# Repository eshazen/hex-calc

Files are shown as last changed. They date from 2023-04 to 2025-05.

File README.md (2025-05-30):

# hex-calc

Simple Hex/Binary/Decimal calculator inspired by HP-16C and TI Programmer.

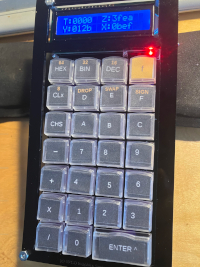
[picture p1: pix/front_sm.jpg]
front view

[large image](pix/front.jpg)

Features:

* Hex / Decimal / Binary display in signed or unsigned mode
  * Entire stack for 8/16 bits, two levels for 32 bits
* four-function two-compliment or unsigned arithmetic
* 8 / 16 / 32 / 64 bit word size
* four-level RPN stack with roll / swap

Runs on ATMeg328 at 8MHz.  Power is 4xAA batteries regulated to 5V.
Industry-standard 16x2 backlit LCD.  Three LEDs:

* Power
* f key (function/shift) active
* signed display mode

Code in <tt>src/calc_hw</tt>.

KiCAD design in <tt>keyboard-pcb</tt>.
<br>Schematic:  [keyboard-pcb.pdf](keyboard-pcb/keyboard-pcb.pdf)

See https://github.com/eshazen/calc-demo-xwin for an X-windows
app written in C which illustrates the general idea.

## Enhancements

Thinking about some added features to support fractional arithmetic
for woodworking.  Display options to round to nearest fraction (1/4,
1/8, 1/16, 1/32, 1/64) and switch between decimal inch, fraction inch
and decimal mm.  Ft/inches another useful display option.

This would involve either floating point or scaled integer math.
For this application the range is pretty limited, maybe 8 ft (~100 in)
max.

Base units could be 2.54e-6 in (1um).  100 inches would require ~25
bits.  

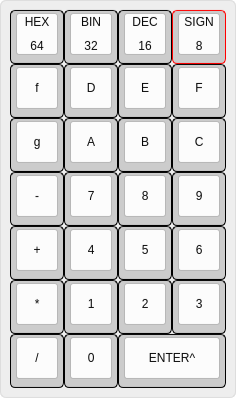
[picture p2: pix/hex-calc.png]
keyboard layout


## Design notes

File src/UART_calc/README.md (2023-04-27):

# UART_calc

This is a test version of the "hex" calculator to test AVR resource use

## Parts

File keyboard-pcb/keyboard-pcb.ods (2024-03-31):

# | Reference | Qty | Value | Footprint | CatNo | Ordered
1 | BT1 | 1 | 4xAAA | AAA_batt_holder:Keystone_4xAAA_2481 | BC4AAAPC-ND | DK
2 | C1, C3 | 2 | 0.1uF | Capacitor_THT:C_Disc_D5.0mm_W2.5mm_P2.50mm
3 | C2 | 1 | 10uF | Capacitor_THT:C_Disc_D5.0mm_W2.5mm_P2.50mm
4 | D1, D2, D11 | 3 | LED | LED_THT:LED_D3.0mm
5 | D3, D4, D5, D6, D7, D8, D9, D10, D12, D13, D14, D15, D16, D17, D18, D19, D20, D21, D22, D23, D24, D25, D26, D27, D28, D29, D30 | 27 | 1N914 | Diode_THT:D_DO-35_SOD27_P7.62mm_Horizontal |  | DK
6 | J1 | 1 | Conn_02x03_Odd_Even | Connector_PinHeader_2.54mm:PinHeader_2x03_P2.54mm_Vertical
7 | R1, R2, R3, R5 | 4 | 470 | Resistor_THT:R_Axial_DIN0207_L6.3mm_D2.5mm_P7.62mm_Horizontal
8 | R4 | 1 | 10k | Resistor_THT:R_Axial_DIN0207_L6.3mm_D2.5mm_P7.62mm_Horizontal
9 | RV1 | 1 | 10k | Potentiometer_THT:Potentiometer_Bourns_3266P_Horizontal |  | DK
10 | SW1, SW2, SW3, SW4, SW6, SW7, SW8, SW9, SW10, SW11, SW12, SW13, SW14, SW15, SW16, SW17, SW18, SW19, SW20, SW21, SW22, SW23, SW24, SW25, SW26, SW27 | 26 | SW_Push | Button_Switch_Keyboard:SW_Cherry_MX_1.00u_PCB |  | Amazon
11 | SW5 | 1 | SW_SPST | my_switch:ANT11TFHQE_switch | 2449-ANT11TFHQE-ND | DK
12 | SW28 | 1 | SW_Push | Button_Switch_Keyboard:SW_Cherry_MX_2.00u_PCB |  | Stock
13 | U2 | 1 | R1500H | Package_TO_SOT_SMD:SOT-89-5_Handsoldering | 2129-R1500H050B-T1-FECT-ND | DK
14 | U3 | 1 | ATmega328-P | Package_DIP:DIP-28_W7.62mm |  | DK
15 | U4 | 1 | RC1602A | Display:WC1602A |  | Amazon

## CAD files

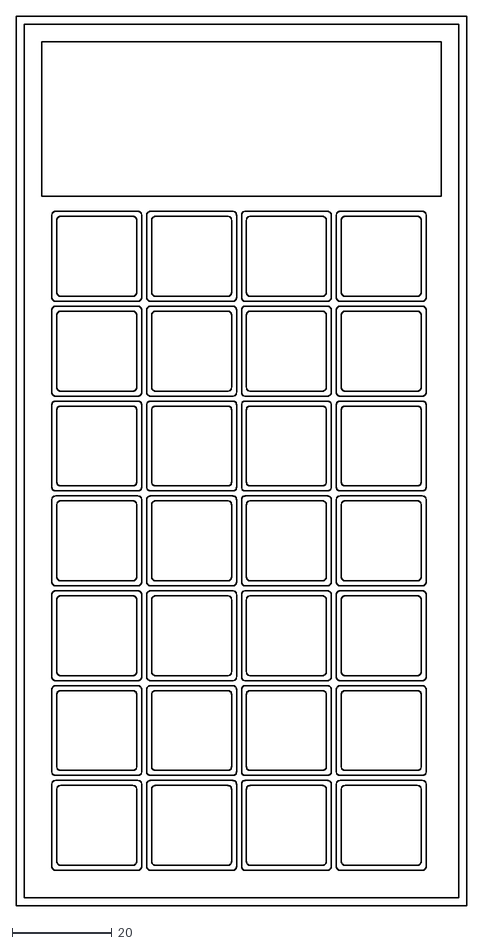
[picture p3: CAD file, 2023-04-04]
3D/calc.dxf
90.2 x 178.2

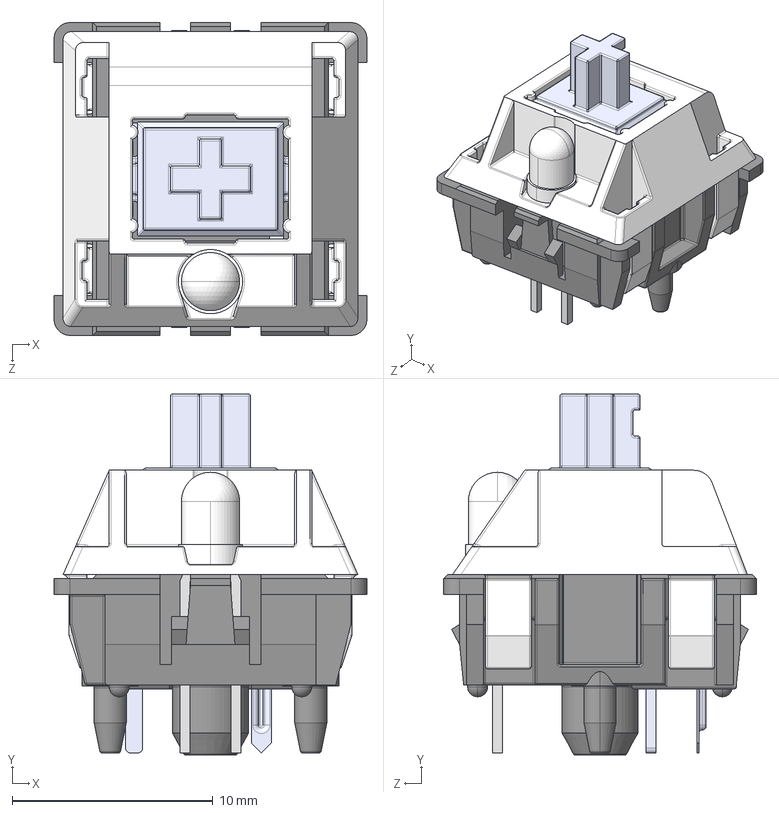
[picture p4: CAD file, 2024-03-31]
keyboard-pcb/3D/Cherry MX.STEP
15.6 x 18.0 x 15.6 mm
Bottom
Pulsador
Top
Pieza5^Cherry MX
Pin1
Pin2
Led 3mm_trans

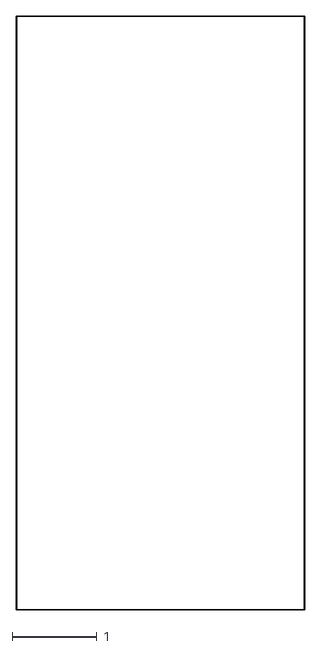
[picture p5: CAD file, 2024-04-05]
keyboard-pcb/DXF/keyboard-pcb-Edge_Cuts.dxf
3.40 x 7.00

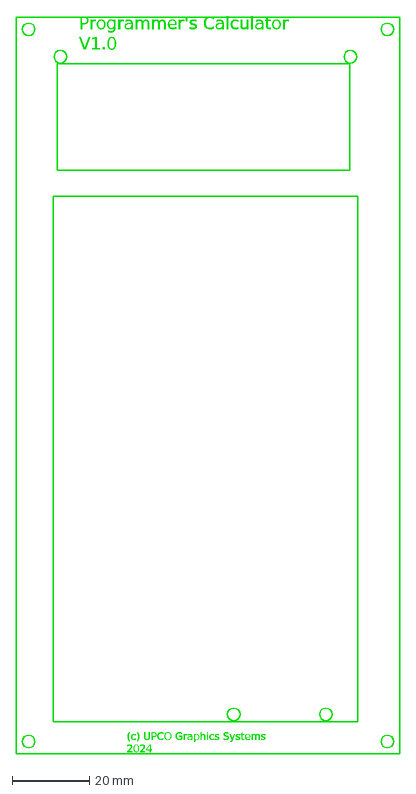
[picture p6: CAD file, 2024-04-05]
keyboard-pcb/DXF/top_plate.dxf
Programmer's Calculator V1.0
(c) UPCO Graphics Systems 2024

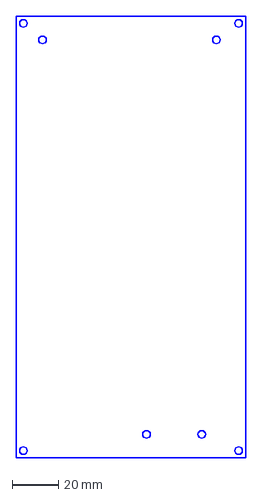
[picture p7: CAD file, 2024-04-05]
keyboard-pcb/DXF/bottom_plate.dxf
99.1 x 190.5 mm

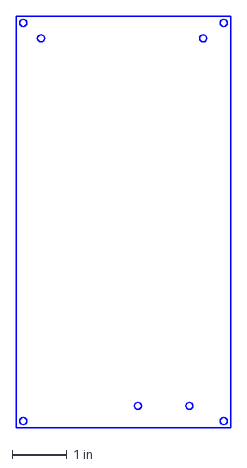
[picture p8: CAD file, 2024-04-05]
keyboard-pcb/DXF/board-mech.dxf
3.90 x 7.50 in

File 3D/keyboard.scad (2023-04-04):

keys = [ [ ["HEX","64"], ["BIN","32"], ["DEC","16"], ["SIGN","8"]],
	 [ ["f", ""],    ["D", ""],    ["E", ""],    ["F", ""]],
	 [ ["g", ""],    ["A", ""],    ["B", ""],    ["C", ""]],
	 [ ["-", ""],    ["7", ""],    ["8", ""],    ["9", ""]],
	 [ ["+", ""],    ["4", ""],    ["5", ""],    ["6", ""]],
	 [ ["*", ""],    ["1", ""],    ["2", ""],    ["3", ""]],
//	 [ ["/", ""],    ["0", ""],    ["ENT", ""],    ["ER", ""]]
	 ];

module keyboard() {

     dx = 19;
     dy = 19;

     x = 0;
     y = 0;

     for( y=[0:len(keys)-1], x=[0:len(keys[y])-1]) {
	  row = keys[y];
	  key = row[x];
//	  echo( "row =", row, " key=", key);
	  translate( [x*dx,-y*dy,0])
	       makeKey( r4_f, r4_b, x1_00, x1_00, key[0], key[1]);
     }

     // last row by hand
     translate( [0, -6*dx, 0]) {
	  makeKey( r4_f, r4_b, x1_00, x1_00, "/");
	  translate( [dx, 0, 0])
	  makeKey( r4_f, r4_b, x1_00, x1_00, "0");
	  translate( [2.5*dx, 0, 0]) {
	       makeKey( r4_f, r4_b, x1_00, x2_00, "ENTER");
	  }
     }
}

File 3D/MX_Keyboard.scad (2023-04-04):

// Cherry MX standard (OEM) measurements
// Measurements and key sizes collected from:
// http://blog.maxkeyboard.com/dwkb/keycap-profile-size-information/
// https://support.wasdkeyboards.com/hc/en-us/articles/115009701328-Keycap-Size-Compatibility
// http://i.imgur.com/K5kui2s.jpg
// Visual information of key text collected from:
// https://www.keychatter.com/wp-content/uploads/2014/07/filco-standard-layout.png
// row number - front and back heights
r1_f = 10.1;
r1_b = 7.9;
r2_f = 9.3;
r2_b = 8;
r3_f = 9.3;
r3_b = 9;
r4_f = 10.8;
r4_b = 11.4;

// width measurement
x1_00 = 18;
x1_25 = 22.8;
x1_50 = 27.5;
x1_75 = 32.3;
x2_00 = 37.1;
x2_25 = 41.8;
x2_75 = 51.4;
space = 118.1;

// spacing measurement
normalSpacing = 12;
spacebarSpacing = 50; // default x6_25
spacebarX6Spacing = 49;
spacebarX6_5Spacing =  52.5;

// other measurements
rounding = 1.5;
postDiam = 5.54;
crossLong = 4.1;
crossWide = 1.35;

// unspecified details
insetX = 5;
insetYfront = 3;
insetYback = 0.6;
wallThick = 1;
postBottomGap = 2;
topCurveDip = 1;

$fn = 36;

// This function borrowed from OpenSCAD Snippet Pad:
// https://openscadsnippetpad.blogspot.com/2017/05/circle-defined-by-three-points.html
// Finding the Center of a Circle from Three Points.
// Points must not be equal or collinear, - lie on a single straight line 
function circle_by_three_points(A, B, C) =
let (
  yD_b = C.y - B.y,  xD_b = C.x - B.x,  yD_a = B.y - A.y,
  xD_a = B.x - A.x,  aS = yD_a / xD_a,  bS = yD_b / xD_b,
  cex = (aS * bS * (A.y - C.y) + 
  bS * (A.x + B.x) -    aS * (B.x + C.x)) / (2 * (bS - aS)),
  cey = -1 * (cex - (A.x + B.x) / 2) / aS + (A.y + B.y) / 2
)
[cex, cey];
    
// Primary entry point for this library
// keyname is a string, as seen in the else-if chain below
module key(keyname) 
{
         if (keyname == "Escape") makeKey(r4_f, r4_b, x1_00, x1_00, "Esc");
    else if (keyname == "F1") makeKey(r4_f, r4_b, x1_00, x1_00, "F1");
    else if (keyname == "F2") makeKey(r4_f, r4_b, x1_00, x1_00, "F2");
    else if (keyname == "F3") makeKey(r4_f, r4_b, x1_00, x1_00, "F3");
    else if (keyname == "F4") makeKey(r4_f, r4_b, x1_00, x1_00, "F4");
    else if (keyname == "F5") makeKey(r4_f, r4_b, x1_00, x1_00, "F5");
    else if (keyname == "F6") makeKey(r4_f, r4_b, x1_00, x1_00, "F6");
    else if (keyname == "F7") makeKey(r4_f, r4_b, x1_00, x1_00, "F7");
    else if (keyname == "F8") makeKey(r4_f, r4_b, x1_00, x1_00, "F8");
    else if (keyname == "F9") makeKey(r4_f, r4_b, x1_00, x1_00, "F9");
    else if (keyname == "F10") makeKey(r4_f, r4_b, x1_00, x1_00, "F10");
    else if (keyname == "F11") makeKey(r4_f, r4_b, x1_00, x1_00, "F11");
    else if (keyname == "F12") makeKey(r4_f, r4_b, x1_00, x1_00, "F12");
    else if (keyname == "Print Screen") makeKey(r4_f, r4_b, x1_00, x1_00, "Print", "Screen");
    else if (keyname == "Scroll Lock") makeKey(r4_f, r4_b, x1_00, x1_00, "Scroll", "Lock");
    else if (keyname == "Pause") makeKey(r4_f, r4_b, x1_00, x1_00, "Pause", "Break");
    else if (keyname == "`") makeKey(r4_f, r4_b, x1_00, x1_00, "~", "`");
    else if (keyname == "1") makeKey(r4_f, r4_b, x1_00, x1_00, "!", "1");
    else if (keyname == "2") makeKey(r4_f, r4_b, x1_00, x1_00, "@", "2");
    else if (keyname == "3") makeKey(r4_f, r4_b, x1_00, x1_00, "#", "3");
    else if (keyname == "4") makeKey(r4_f, r4_b, x1_00, x1_00, "$", "4");
    else if (keyname == "5") makeKey(r4_f, r4_b, x1_00, x1_00, "%", "5");
    else if (keyname == "6") makeKey(r4_f, r4_b, x1_00, x1_00, "^", "6");
    else if (keyname == "7") makeKey(r4_f, r4_b, x1_00, x1_00, "&", "7");
    else if (keyname == "8") makeKey(r4_f, r4_b, x1_00, x1_00, "*", "8");
    else if (keyname == "9") makeKey(r4_f, r4_b, x1_00, x1_00, "(", "9");
    else if (keyname == "0") makeKey(r4_f, r4_b, x1_00, x1_00, ")", "0");
    else if (keyname == "-") makeKey(r4_f, r4_b, x1_00, x1_00, "_", "-");
    else if (keyname == "=") makeKey(r4_f, r4_b, x1_00, x1_00, "+", "=");
    else if (keyname == "Backspace") makeKey(r4_f, r4_b, x1_00, x2_00, "◄ Backspace", "", normalSpacing);
    else if (keyname == "Insert") makeKey(r4_f, r4_b, x1_00, x1_00, "Insert");
    else if (keyname == "Home") makeKey(r4_f, r4_b, x1_00, x1_00, "Home");
    else if (keyname == "Page Up") makeKey(r4_f, r4_b, x1_00, x1_00, "Page", "Up");
    else if (keyname == "Num Lock") makeKey(r4_f, r4_b, x1_00, x1_00, "Num", "Lock");
    else if (keyname == "Num /") makeKey(r4_f, r4_b, x1_00, x1_00, "/");
    else if (keyname == "Num *") makeKey(r4_f, r4_b, x1_00, x1_00, "*");
    else if (keyname == "Num -") makeKey(r4_f, r4_b, x1_00, x1_00, "-");
    else if (keyname == "Tab") makeKey(r3_f, r3_b, x1_00, x1_50, "Tab");
    else if (keyname == "Q") makeKey(r3_f, r3_b, x1_00, x1_00, "Q", " ");
    else if (keyname == "W") makeKey(r3_f, r3_b, x1_00, x1_00, "W", " ");
    else if (keyname == "E") makeKey(r3_f, r3_b, x1_00, x1_00, "E", " ");
    else if (keyname == "R") makeKey(r3_f, r3_b, x1_00, x1_00, "R", " ");
    else if (keyname == "T") makeKey(r3_f, r3_b, x1_00, x1_00, "T", " ");
    else if (keyname == "Y") makeKey(r3_f, r3_b, x1_00, x1_00, "Y", " ");
    else if (keyname == "U") makeKey(r3_f, r3_b, x1_00, x1_00, "U", " ");
    else if (keyname == "I") makeKey(r3_f, r3_b, x1_00, x1_00, "I", " ");
    else if (keyname == "O") makeKey(r3_f, r3_b, x1_00, x1_00, "O", " ");
    else if (keyname == "P") makeKey(r3_f, r3_b, x1_00, x1_00, "P", " ");
    else if (keyname == "[") makeKey(r3_f, r3_b, x1_00, x1_00, "{", "[");
    else if (keyname == "]") makeKey(r3_f, r3_b, x1_00, x1_00, "}", "]");
    else if (keyname == "\\") makeKey(r3_f, r3_b, x1_00, x1_50, "|", "\\");
    else if (keyname == "Delete") makeKey(r3_f, r3_b, x1_00, x1_00, "Delete");
    else if (keyname == "End") makeKey(r3_f, r3_b, x1_00, x1_00, "End");
    else if (keyname == "Page Down") makeKey(r3_f, r3_b, x1_00, x1_00, "Page", "Down");
    else if (keyname == "Num 7") makeKey(r3_f, r3_b, x1_00, x1_00, "7", "Home");
    else if (keyname == "Num 8") makeKey(r3_f, r3_b, x1_00, x1_00, "8", "▲");
    else if (keyname == "Num 9") makeKey(r3_f, r3_b, x1_00, x1_00, "9", "Pg Up");
    else if (keyname == "Num +") makeKey(r2_f, r3_b, x2_00, x1_00, "+", "", normalSpacing, "vertical");
    else if (keyname == "Caps Lock") makeKey(r2_f, r2_b, x1_00, x1_50, "CapsLock");
    else if (keyname == "A") makeKey(r2_f, r2_b, x1_00, x1_00, "A", " ");
    else if (keyname == "S") makeKey(r2_f, r2_b, x1_00, x1_00, "S", " ");
    else if (keyname == "D") makeKey(r2_f, r2_b, x1_00, x1_00, "D", " ");
    else if (keyname == "F") makeKey(r2_f, r2_b, x1_00, x1_00, "F", "     _");
    else if (keyname == "G") makeKey(r2_f, r2_b, x1_00, x1_00, "G", " ");
    else if (keyname == "H") makeKey(r2_f, r2_b, x1_00, x1_00, "H", " ");
    else if (keyname == "J") makeKey(r2_f, r2_b, x1_00, x1_00, "J", "     _");
    else if (keyname == "K") makeKey(r2_f, r2_b, x1_00, x1_00, "K", " ");
    else if (keyname == "L") makeKey(r2_f, r2_b, x1_00, x1_00, "L", " ");
    else if (keyname == ";") makeKey(r2_f, r2_b, x1_00, x1_00, ":", ";");
    else if (keyname == "'") makeKey(r2_f, r2_b, x1_00, x1_00, "'", "\"");
    else if (keyname == "Enter") makeKey(r2_f, r2_b, x1_00, x2_25, "Enter", "", normalSpacing);
    else if (keyname == "Num 4") makeKey(r2_f, r2_b, x1_00, x1_00, "4", "◄");
    else if (keyname == "Num 5") makeKey(r2_f, r2_b, x1_00, x1_00, "5", "     _");
    else if (keyname == "Num 6") makeKey(r2_f, r2_b, x1_00, x1_00, "6", "►");
    else if (keyname == "Left Shift") makeKey(r1_f, r1_b, x1_00, x2_25, "Shift", "", normalSpacing);
    else if (keyname == "Z") makeKey(r1_f, r1_b, x1_00, x1_00, "Z", " ");
    else if (keyname == "X") makeKey(r1_f, r1_b, x1_00, x1_00, "X", " ");
    else if (keyname == "C") makeKey(r1_f, r1_b, x1_00, x1_00, "C", " ");
    else if (keyname == "V") makeKey(r1_f, r1_b, x1_00, x1_00, "V", " ");
    else if (keyname == "B") makeKey(r1_f, r1_b, x1_00, x1_00, "B", " ");
    else if (keyname == "N") makeKey(r1_f, r1_b, x1_00, x1_00, "N", " ");
    else if (keyname == "M") makeKey(r1_f, r1_b, x1_00, x1_00, "M", " ");
    else if (keyname == ",") makeKey(r1_f, r1_b, x1_00, x1_00, "<", ",");
    else if (keyname == ".") makeKey(r1_f, r1_b, x1_00, x1_00, ">", ".");
    else if (keyname == "/") makeKey(r1_f, r1_b, x1_00, x1_00, "?", "/");
    else if (keyname == "Right Shift") makeKey(r1_f, r1_b, x1_00, x2_75, "Shift", "", normalSpacing);
    else if (keyname == "Up") makeKey(r1_f, r1_b, x1_00, x1_00, "▲");
    else if (keyname == "Num 1") makeKey(r1_f, r1_b, x1_00, x1_00, "1", "End");
    else if (keyname == "Num 2") makeKey(r1_f, r1_b, x1_00, x1_00, "2", "▼");
    else if (keyname == "Num 3") makeKey(r1_f, r1_b, x1_00, x1_00, "3", "Pg Dn");
    else if (keyname == "Num Enter") makeKey(r1_f, r1_b, x2_00, x1_00, "Enter", "", normalSpacing, "vertical");
    else if (keyname == "Ctrl") makeKey(r1_f, r1_b, x1_00, x1_25, "Ctrl");
    else if (keyname == "Win") makeKey(r1_f, r1_b, x1_00, x1_25, "Win");
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

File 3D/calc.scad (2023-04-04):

include <MX_Keyboard.scad>
include <keyboard.scad>
include <lcd.scad>

pcb_wid = 87;
pcb_len = 175;
pcb_thk = 1.6;

case_thk = 1.6;
case_hgt = 15;

module case() {
     color("green") cube( [pcb_wid, pcb_len, pcb_thk]);
     translate( [-case_thk, -case_thk, -2]) {
	  cube( [case_thk, pcb_len+2*case_thk, case_hgt]);
	  translate( [pcb_wid+case_thk, 0, 0])
	       cube( [case_thk, pcb_len+2*case_thk, case_hgt]);
	  cube( [pcb_wid+2*case_thk, case_thk, case_hgt]);
	  translate( [0, pcb_len+case_thk, 0])
	       cube( [pcb_wid+2*case_thk, case_thk, case_hgt]);
     }
}


module calcu() {

     translate( [0.5*19, 6.5*19, 0]) {
	  color("lightblue")
	       keyboard();
	  translate( [-11, 12, 0])
	       color("grey")
	       lcd();
     }
     translate( [-5, -5, -2]) {
	  case();
     }
}

// projection( cut=true)
calcu();

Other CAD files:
3D/cherry.scad
3D/lcd.scad
case/bottom.scad
keyboard-pcb/3D/ct_ant11tfhqe.scad
keyboard-pcb/DXF/keyboard-pcb-F_Mask.dxf
keyboard-pcb/DXF/keyboard-pcb-F_Silkscreen.dxf

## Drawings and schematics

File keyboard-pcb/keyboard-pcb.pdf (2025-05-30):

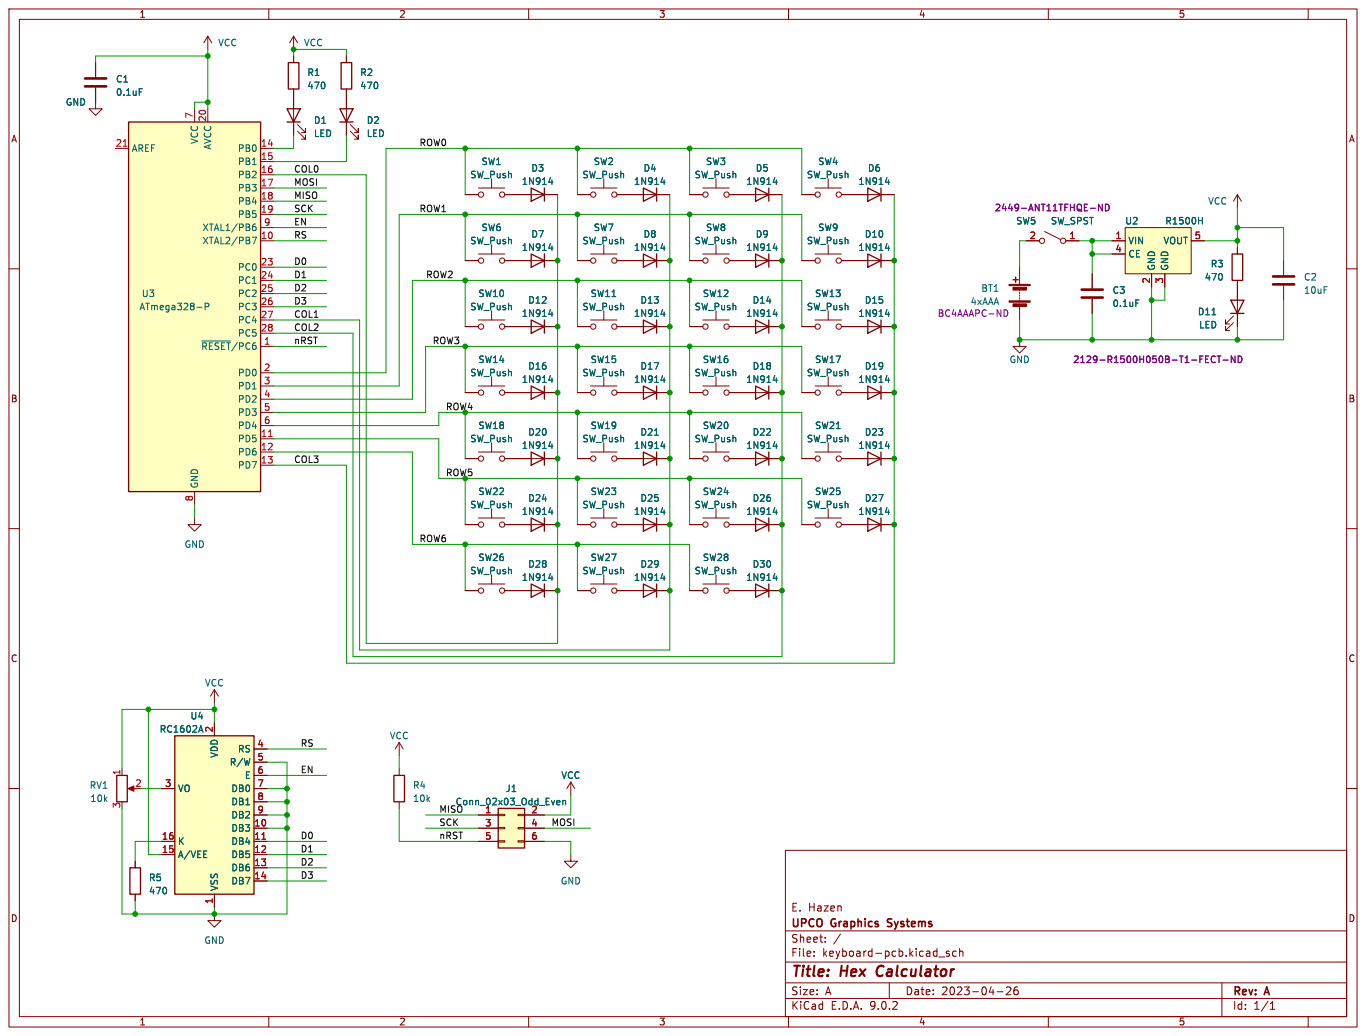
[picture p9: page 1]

8 AVCC 20 PB0 14 PB1 15 PB2 16 PB3 17 PB4 18 PB5 19 XTAL1/PB6 9 XTAL2/PB7 10 PC0 23 PC1 24 PC2 25 PC3 26 PC4 27 PC5 28 ~{RESET}/PC61 PD0 2 PD1 3 PD2 4 PD3 5 PD4 6 PD5 11 PD6 12 PD7 13 U3 ATmega328-P GND GND

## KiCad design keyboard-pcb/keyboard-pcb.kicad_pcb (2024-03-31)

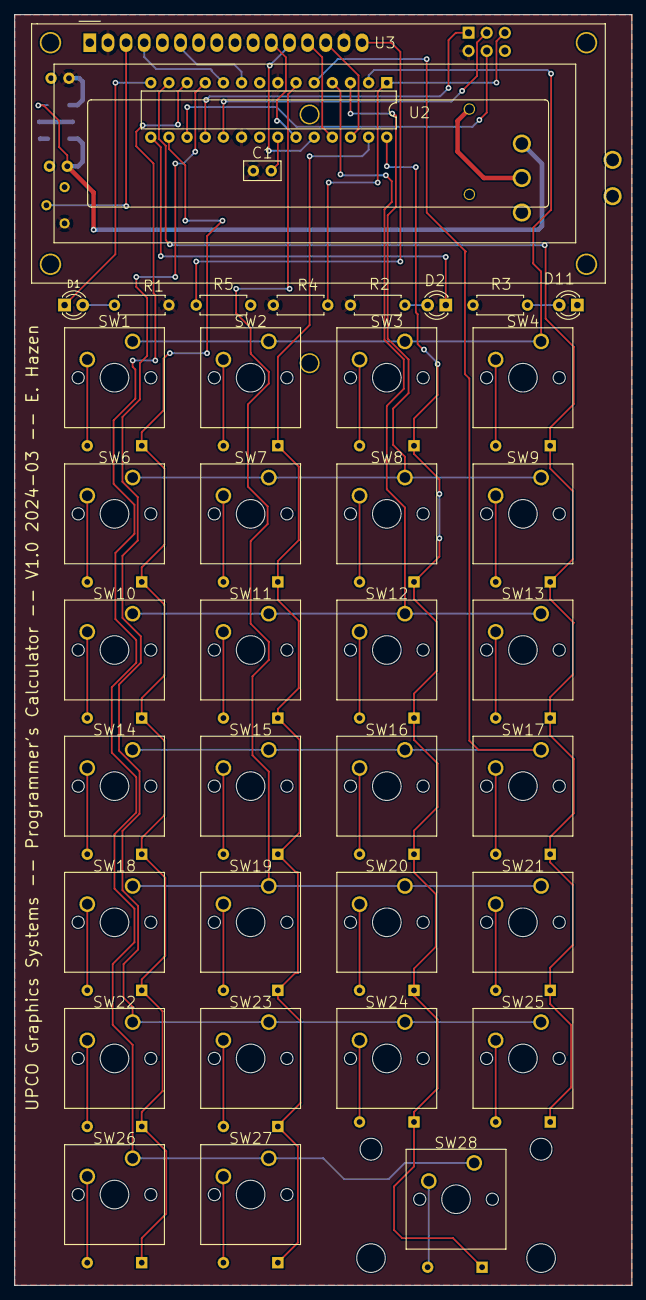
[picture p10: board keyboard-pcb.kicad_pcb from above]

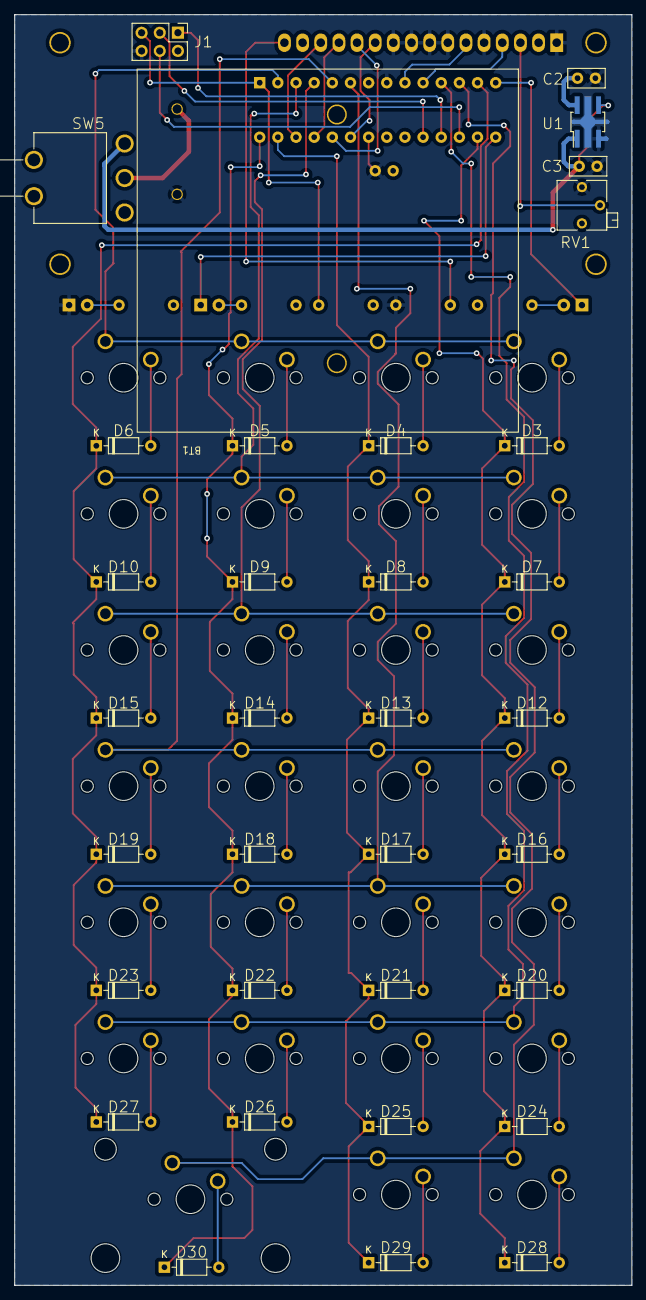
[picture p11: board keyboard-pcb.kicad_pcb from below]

Board: 2 copper layers, 86.4 x 177.8 mm, 72 parts (34 on the bottom side), 59 nets.

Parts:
BT1: 4xAAA; Keystone_4xAAA_2481
C1, C3: 0.1uF; C_Disc_D5.0mm_W2.5mm_P2.50mm
C2: 10uF; C_Disc_D5.0mm_W2.5mm_P2.50mm
D1, D2, D11: LED; LED_D3.0mm
D3, D4, D5, D6, D7, D8, D9, D10, D12, D13, D14, D15, D16, D17, D18, D19, D20, D21, D22, D23, D24, D25, D26, D27, D28, D29, D30: 1N914; D_DO-35_SOD27_P7.62mm_Horizontal
J1: Conn_02x03_Odd_Even; PinHeader_2x03_P2.54mm_Vertical
R1, R2, R3, R5: 470; R_Axial_DIN0207_L6.3mm_D2.5mm_P7.62mm_Horizontal
R4: 10k; R_Axial_DIN0207_L6.3mm_D2.5mm_P7.62mm_Horizontal
RV1: 10k; Potentiometer_Bourns_3266P_Horizontal
SW1, SW2, SW3, SW4, SW6, SW7, SW8, SW9, SW10, SW11, SW12, SW13, SW14, SW15, SW16, SW17, SW18, SW19, SW20, SW21, SW22, SW23, SW24, SW25, SW26, SW27: SW_Push; SW_Cherry_MX_1.00u_PCB
SW5: SW_SPST; ANT11TFHQE_switch
SW28: SW_Push; SW_Cherry_MX_2.00u_PCB
U1: R1500H; SOT-89-5_Handsoldering
U2: ATmega328-P; DIP-28_W7.62mm
U3: RC1602A; WC1602A

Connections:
/COL0: D3.1 (K), D7.1 (K), D12.1 (K), D16.1 (K), D20.1 (K), D24.1 (K), D28.1 (K), U2.16 (PB2)
/COL1: D4.1 (K), D8.1 (K), D13.1 (K), D17.1 (K), D21.1 (K), D25.1 (K), D29.1 (K), U2.27 (PC4)
/COL2: D5.1 (K), D9.1 (K), D14.1 (K), D18.1 (K), D22.1 (K), D26.1 (K), D30.1 (K), U2.28 (PC5)
/COL3: D6.1 (K), D10.1 (K), D15.1 (K), D19.1 (K), D23.1 (K), D27.1 (K), U2.13 (PD7)
/D0: U2.23 (PC0), U3.11 (DB4)
/D1: U2.24 (PC1), U3.12 (DB5)
/D2: U2.25 (PC2), U3.13 (DB6)
/D3: U2.26 (PC3), U3.14 (DB7)
/EN: U2.9 (XTAL1/PB6), U3.6 (E)
/MISO: J1.1, U2.18 (PB4)
/MOSI: J1.4, U2.17 (PB3)
/ROW0: SW1.1, SW2.1, SW3.1, SW4.1, U2.2 (PD0)
/ROW1: SW6.1, SW7.1, SW8.1, SW9.1, U2.3 (PD1)
/ROW2: SW10.1, SW11.1, SW12.1, SW13.1, U2.4 (PD2)
/ROW3: SW14.1, SW15.1, SW16.1, SW17.1, U2.5 (PD3)
/ROW4: SW18.1, SW19.1, SW20.1, SW21.1, U2.6 (PD4)
/ROW5: SW22.1, SW23.1, SW24.1, SW25.1, U2.11 (PD5)
/ROW6: SW26.1, SW27.1, SW28.1, U2.12 (PD6)
/RS: U2.10 (XTAL2/PB7), U3.4 (RS)
/SCK: J1.3, U2.19 (PB5)
/nRST: J1.5, R4.2, U2.1 (~RESET/PC6)
GND: BT1.2 (-), C1.2, C2.2, C3.2, D11.1 (K), J1.6, R5.2, RV1.3, U1.2 (GND), U1.3 (GND), U2.8 (GND), U2.22 (GND), U3.1 (VSS), U3.5 (R/W), U3.7 (DB0), U3.8 (DB1), U3.9 (DB2), U3.10 (DB3)
unnamed: BT1.1 (+), SW5.2 (B)
unnamed: D1.2 (A), R1.2
unnamed: D1.1 (K), U2.14 (PB0)
unnamed: D2.2 (A), R2.2
unnamed: D2.1 (K), U2.15 (PB1)
unnamed: D3.2 (A), SW1.2
unnamed: D4.2 (A), SW2.2
unnamed: D5.2 (A), SW3.2
unnamed: D6.2 (A), SW4.2
unnamed: D7.2 (A), SW6.2
unnamed: D8.2 (A), SW7.2
unnamed: D9.2 (A), SW8.2
unnamed: D10.2 (A), SW9.2
unnamed: D11.2 (A), R3.2
unnamed: D12.2 (A), SW10.2
unnamed: D13.2 (A), SW11.2
unnamed: D14.2 (A), SW12.2
unnamed: D15.2 (A), SW13.2
unnamed: D16.2 (A), SW14.2
unnamed: D17.2 (A), SW15.2
unnamed: D18.2 (A), SW16.2
unnamed: D19.2 (A), SW17.2
unnamed: D20.2 (A), SW18.2
unnamed: D21.2 (A), SW19.2
unnamed: D22.2 (A), SW20.2
unnamed: D23.2 (A), SW21.2
unnamed: D24.2 (A), SW22.2
unnamed: D25.2 (A), SW23.2
unnamed: D26.2 (A), SW24.2
unnamed: D27.2 (A), SW25.2
unnamed: D28.2 (A), SW26.2
unnamed: D29.2 (A), SW27.2
unnamed: D30.2 (A), SW28.2
unnamed: C3.1, SW5.1 (A), U1.1 (VIN), U1.4 (CE)
unnamed: R5.1, U3.16 (K)
unnamed: RV1.2, U3.3 (VO)
VCC: C1.1, C2.1, J1.2, R1.1, R2.1, R3.1, R4.1, RV1.1, U1.5 (VOUT), U2.7 (VCC), U2.20 (AVCC), U3.2 (VDD), U3.15 (A/VEE)

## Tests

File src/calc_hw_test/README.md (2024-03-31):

# calc_hw_test

hardware test for calculator board

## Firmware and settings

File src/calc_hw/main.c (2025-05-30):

/*
 * hex calculator for target hardware
 */
#define CALC_TOP_MAIN

#include <stdio.h>
#include <avr/io.h>
#include <util/delay.h>
#include "lcd.h"
#include "kb.h"
#include "timer.h"
#include "led.h"
#include "calc.h"
#include "calc_key.h"
#include "custom.h"

// #define DEBUG_KEY

// universal LCD display buffer
char msg[LCD_WID+2];

extern uint8_t kb_val[];

int main (void)
{
  lcd_init();
  led_init();
  kb_init();

  load_custom_char();

  timer_setup();
  sei();			/* enable interrups */

  lcd_puts( "Hex calc V0.2");
  lcd_addr( 0x40);
  for( uint8_t i=1; i<=8; i++)
    lcd_putc( i);
  

  _delay_ms( 1000);
  lcd_cls();

  // set some defaults
  radix = DEF_RADIX;		/* radix */
  wsize = DEF_SIZE;		/* size */

  sign = 0;			/* unsigned */
  push = 0;

  while( 1) {

    uint32_t ms = get_millis();

    // poll KB every 1 ms
    if( ms != get_millis())
      poll_kb();
      
    // check/update display every 256 ms
    if( !(ms & 255)) {

      int k = get_kb();

      if( k) {
#ifdef DEBUG_KEY
      // display key code
      lcd_addr( 0);
      snprintf( msg, sizeof(msg), "key: %c (%02x) ", shift ? 'S' : 'N', k);
      lcd_puts( msg);
      _delay_ms(500);
#endif
	calc_key( k);
      } // if(k)

	// set LEDs
      set_led( 0, shift);
      set_led( 1, sign);

    } // 255 ms

  }

}

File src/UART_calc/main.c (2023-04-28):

/*
 * very simple 4-function decimal calculator to test low-level stuff
 * should work on AVR or desktop
 */

#include <stdio.h>
#include <string.h>
#include <inttypes.h>
#include <ctype.h>
#include <stdlib.h>

//---- set up for character-by-character I/O ----

#ifdef AVR
#include <util/delay.h>
#include <avr/io.h>
#include "uart.h"
// Arduino LED is on PB5
#define LED_DDR DDRB
#define LED_BIT 5
#define LED_PORT PORTB
// create a file pointer for read/write to USART0
FILE usart0_str = FDEV_SETUP_STREAM(USART0SendByte, USART0ReceiveByte, _FDEV_SETUP_RW);

#define tty_ready() USART0CharacterAvailable()
#define tty_char() USART0ReceiveByte(NULL)

#else

#include "calc-src/tty_helper.h"

#endif
//-------------------------------------------------

// buffer for converted values for printing
static char sval[21];
// the stack
static int64_t x, y, z;

// convert uint64 to string (from KamilCuk on stackoverflow)
char *uint64_to_str(uint64_t n, char dest[21] ) {
  dest += 20;
  *dest-- = 0;
  while (n) {
    *dest-- = (n % 10) + '0';
    n /= 10;
  }
  return dest + 1;
}

static int c;
char *op;
char *val;

int main (void)
{

  //---- initialize character-by-character input mode ----
#ifdef AVR
  USART0Init();
  stdout = &usart0_str;		/* connect UART to stdout */
  stdin = &usart0_str;		/* connect UART to stdin */

  LED_DDR ^= (1 << LED_BIT);
#else
  tty_raw();
#endif
  
  puts("UART test");

  while( 1) {

    // collect characters and process them
    c = tty_char();
#ifndef AVR
    if( c == 3)
      exit(1);
#endif    

    if( isxdigit(c)) {
      if( isdigit(c))
	c -= '0';
      else
	c -= toupper(c) - 'A' + 1;
      x = x * 10LL + c;

    } else if( (op = strchr( "+-*/", c))) {

      switch( *op) {
      case '+':
	x = x + y;
	break;
      case '-':
	x = y - x;
	break;
      case '*':
	x = x * y;
	break;
      case '/':
	x = y / x;
	break;
      }
      
    } else if( c == 13 || c == 10) {
      z = y;
      y = x;
      x = 0;
    }

    // update display
    val = uint64_to_str( z, sval);
    printf("Z: %s\n", val);
    val = uint64_to_str( y, sval);
    printf("Y: %s\n", val);
    val = uint64_to_str( x, sval);
    printf("X: %s\n", val);
    puts( "----");
  }
}

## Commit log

2023-04-04 3D model
    [MX_Keyboard.scad, calc.dxf, calc.scad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]
2023-04-26 starting cherry keyboard
    [keyboard-pcb.kicad_pcb, keyboard-pcb.kicad_sch]
2023-04-26 placement in progress
    [keyboard-pcb.kicad_pcb, keyboard-pcb.kicad_sch]
2023-04-27 working on placement
    [keyboard-pcb.kicad_pcb, keyboard-pcb.kicad_sch]
2023-04-27 starting software
    [keyboard-pcb.kicad_pcb, keyboard-pcb.kicad_sch]
2023-04-28 placement done?
    [keyboard-pcb.kicad_pcb, keyboard-pcb.kicad_sch]
2023-05-17 change to AAA, software updates
    [keyboard-pcb-Edge_Cuts.dxf, keyboard-pcb-F_Silkscreen.dxf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]
2023-05-17 V1 ready to order?
    [keyboard-pcb-B_Cu.gbr, keyboard-pcb-B_Mask.gbr, keyboard-pcb-B_Silkscreen.gbr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]
2024-03-28 add 3D cherry model
    [Cherry MX.STEP, keyboard-pcb.kicad_pcb, keyboard-pcb.kicad_sch]
2024-03-31 Rev1 PCB as built; debugging keyboard software
    [keyboard-pcb-B_Cu.gbr, keyboard-pcb-B_Mask.gbr, keyboard-pcb-B_Silkscreen.gbr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]
2024-04-07 fixed insert_every() but unknown issue
    [main.c]
2025-05-30 add schematic PDF
